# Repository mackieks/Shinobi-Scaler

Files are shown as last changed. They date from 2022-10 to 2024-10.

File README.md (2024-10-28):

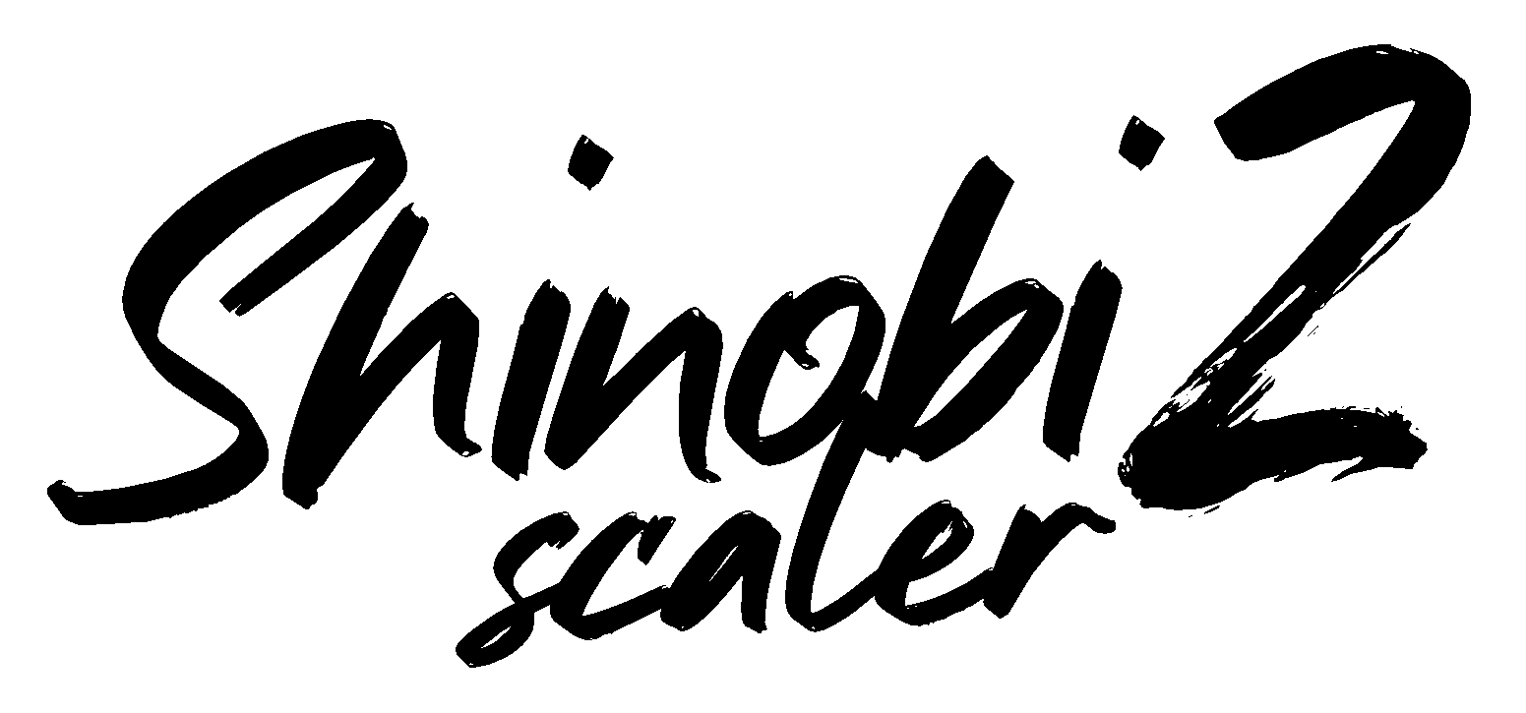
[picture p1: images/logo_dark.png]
<picture> <source media="(prefers-color-scheme: dark)" srcset="https://github.com/mackieks/Shinobi-Scaler/blob/shinobi-2/images/logo_light.png">  </picture> 

Shinobi Scaler 2 is a reimagined, miniaturized GBS8200 for portablizers. Like the original GBS8200, it can convert 240p and 480i RGBs to 480p/720p/960p/1080p VGA, making it perfect for connecting retro video game consoles to modern LCDs.

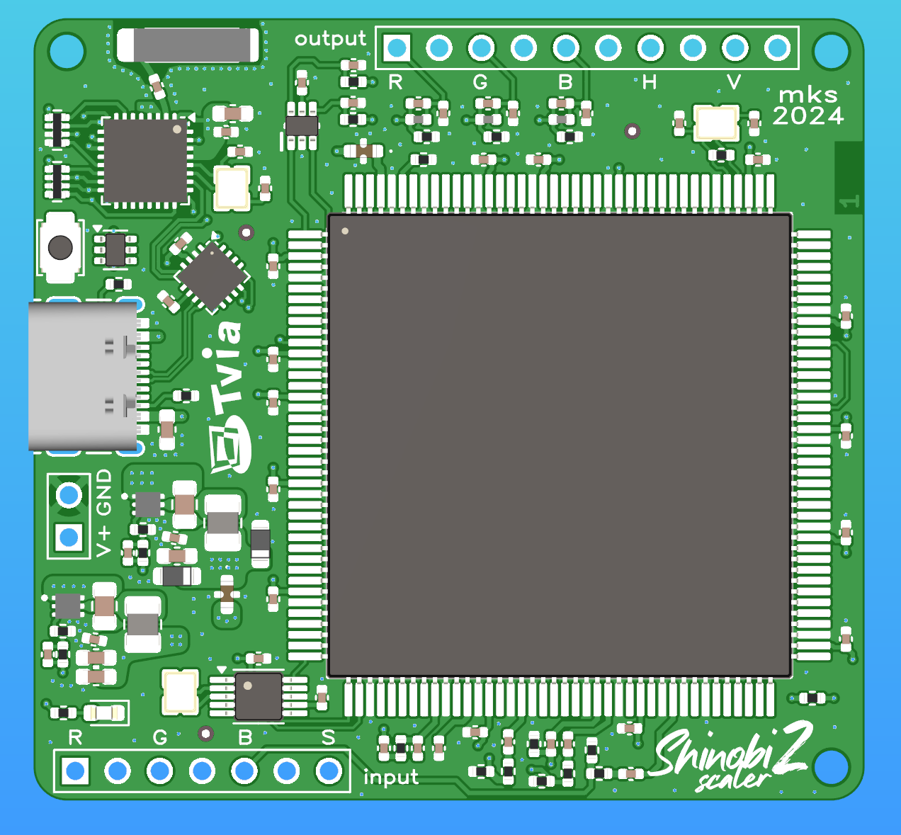
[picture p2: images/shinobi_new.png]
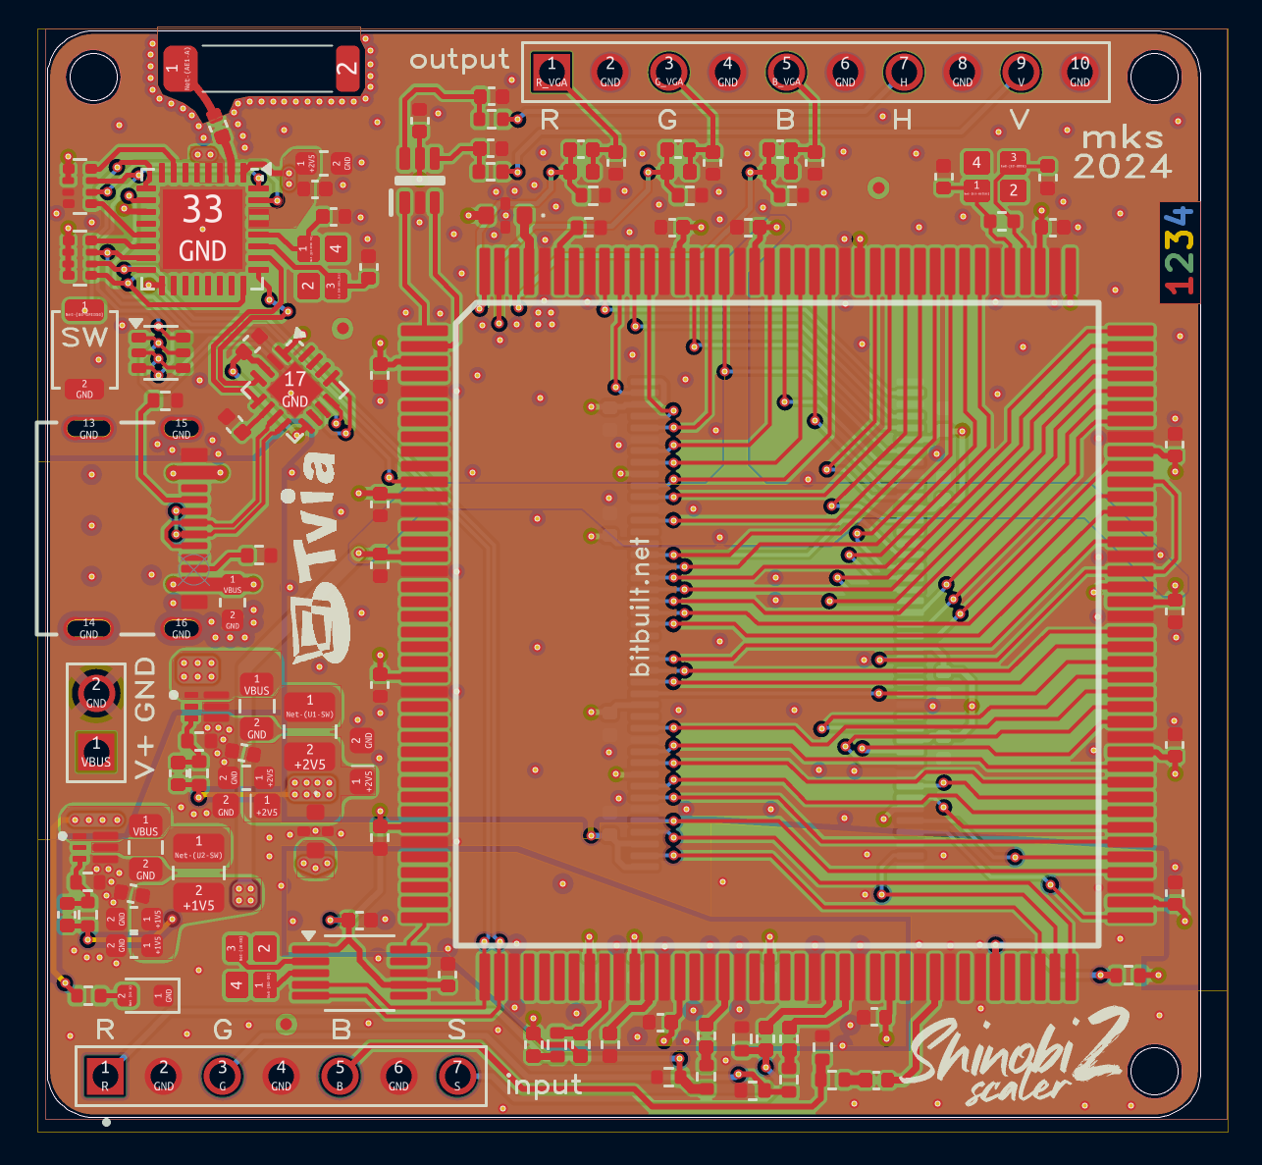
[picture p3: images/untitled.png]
  

## Features
- [x] 50 x 47mm 4-layer PCB (designed in KiCAD 8.99)
- [x] Compatible with [rama's GBS-Control](https://github.com/ramapcsx2/gbs-control)
- [x] 240p/480i RGBs input; 480p/720p/960p/1080p RGBHV/VGA/YPbPr output
- [x] 0.1" PTHs for power and IO (can be mounted with pin headers on a carrier PCB)
- [x] TV5725 scaler IC and 64Mbit SDRAM from GBS8200
- [x] Integrated ESP8285 with Wi-Fi chip antenna
- [x] Integrated CH343P for programming
- [x] Integrated Si5351A clock generator
- [x] Power from any 2.5V - 5.5V source (including 1S li-ion)
- [x] Draws 1.2W, half the power of Shinobi 1!


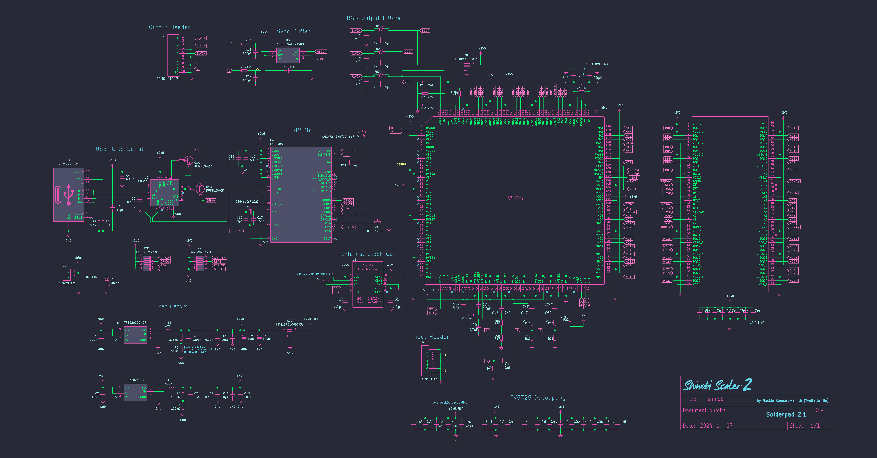
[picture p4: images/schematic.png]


## Gallery
Shinobi 2 PCB

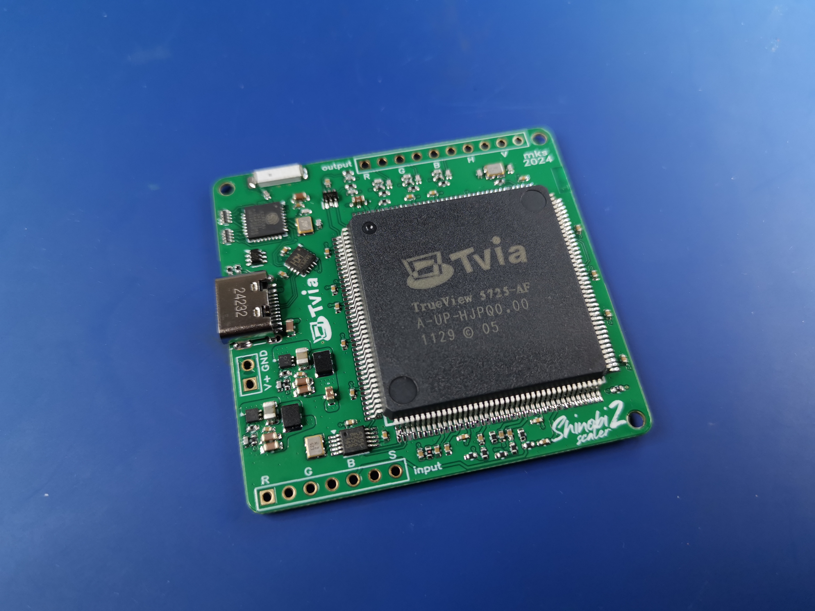
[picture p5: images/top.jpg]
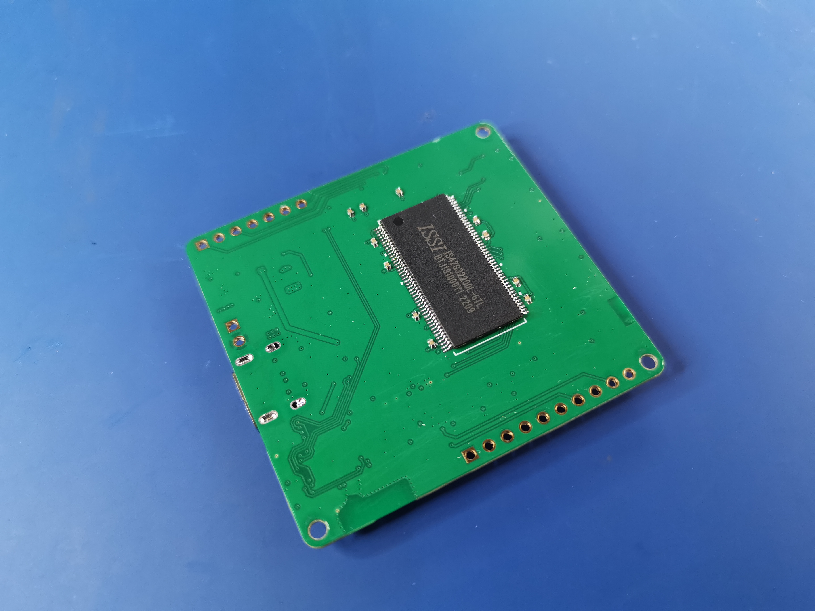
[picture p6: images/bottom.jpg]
  

1Chip SNES RGBs upscaled to 640x480 VGA, displayed on ZJ050NA-08C LCD

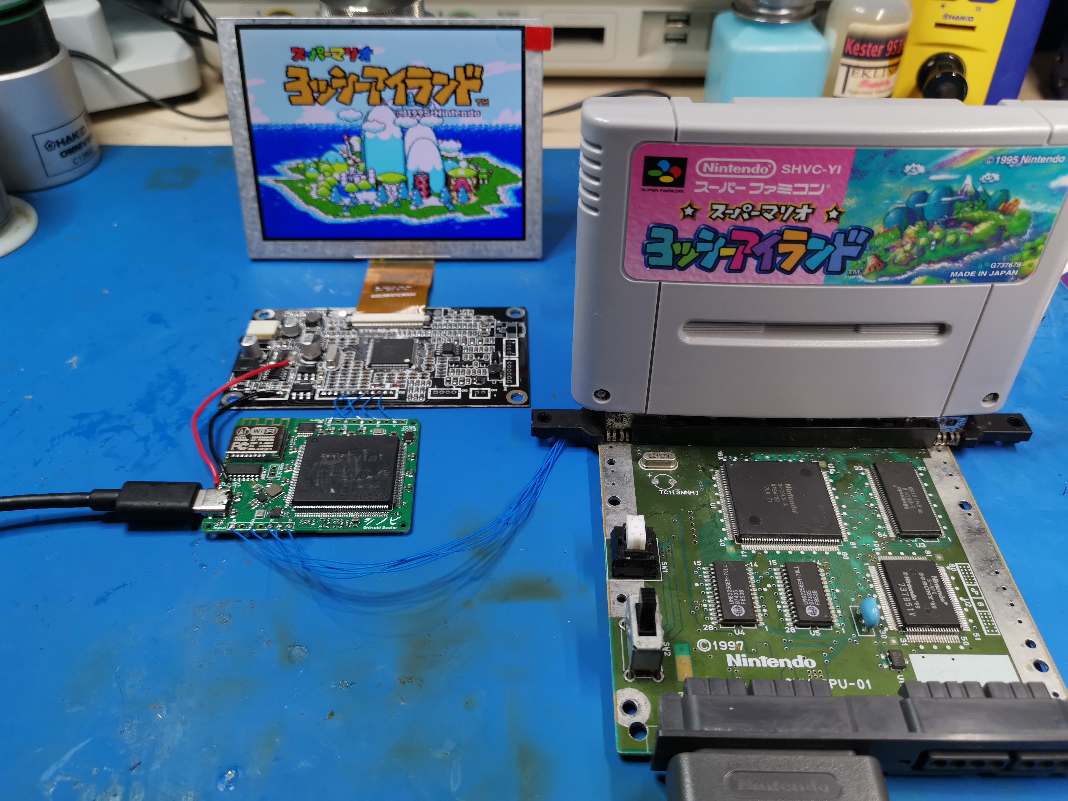
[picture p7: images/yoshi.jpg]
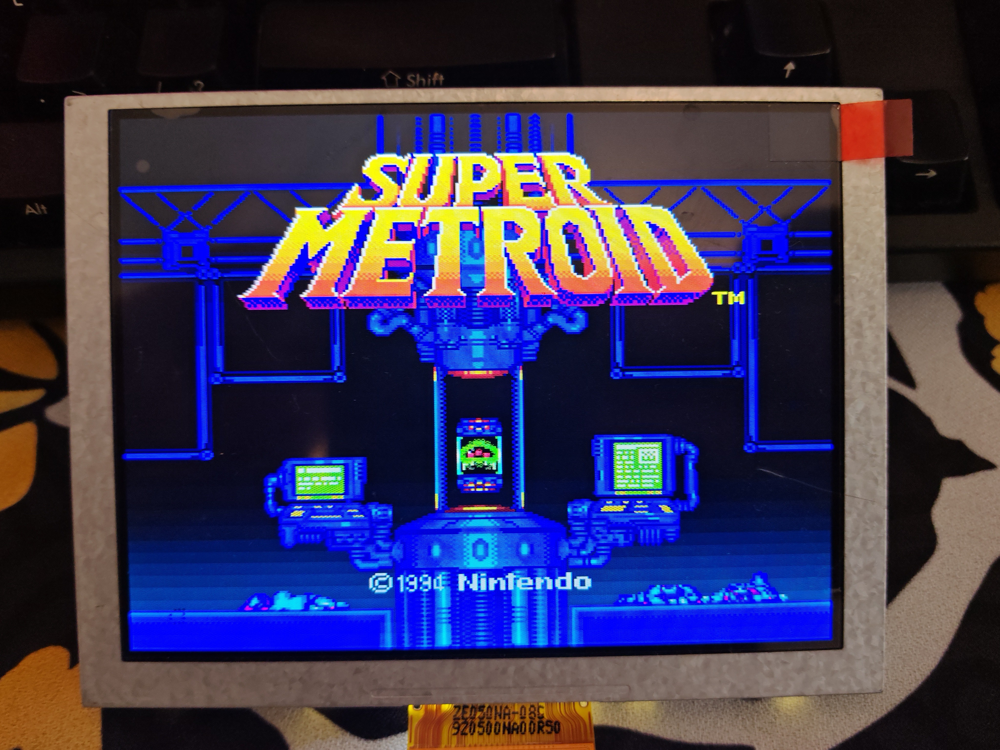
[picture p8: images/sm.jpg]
 

Shinobi 2 testing and power measurement

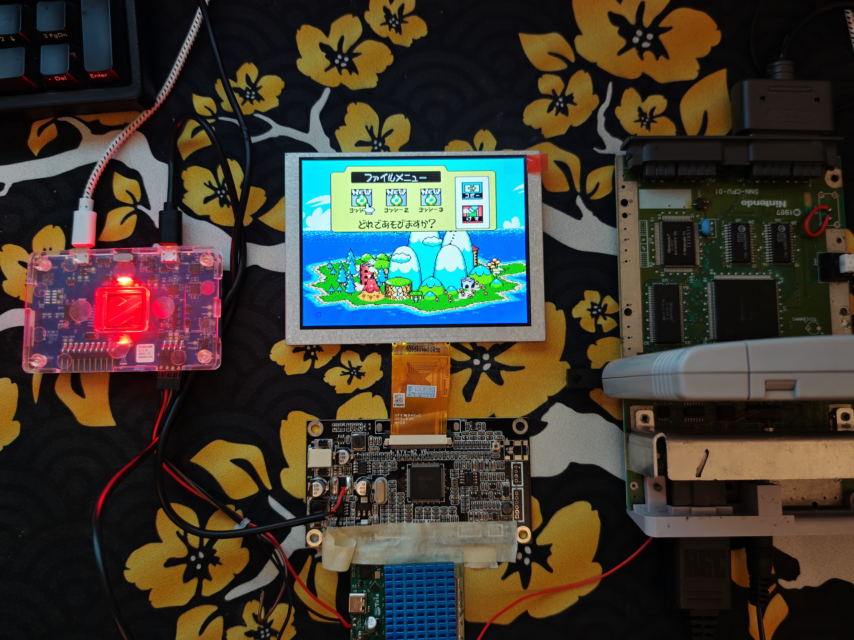
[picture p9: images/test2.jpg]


## Ordering
Recommended fabrication specs:
- 1mm-thick 4-layer PCB
- ENIG finish
- Solderpaste stencil for top side highly recommended

I maintain a [Mouser project](https://www.mouser.com/ProjectManager/ProjectDetail.aspx?AccessID=5e7ab48fda) with most of the BOM. 

You will still need to source a TV5725 and CH343P elsewhere. Cheap GBS8200s are available from AliExpress, eBay, DHGate, and Amazon if you'd like to harvest the TV5725 and SDRAM from one. [TV5725s](https://www.aliexpress.us/item/3256807282171835.html) are available from AliExpress. CH343Ps are sold on [LCSC](https://www.lcsc.com/product-detail/USB-ICs_WCH-Jiangsu-Qin-Heng-CH343P_C2846043.html) and [AliExpress](https://www.aliexpress.us/item/3256806693647102.html).

## Assembly
A ``bom.html`` file is included to facilitate assembly. Open it in your web browser and enjoy.

For a guide on how to assemble PCBs at home using a solderpaste stencil and hot plate, please see [this document from the Thundervolt repo.](https://github.com/mackieks/thundervolt/blob/main/hardware/ASSEMBLY.md)

## Programming
- Install the [CH343P driver](https://www.wch-ic.com/downloads/CH343SER_EXE.html).
- Plug USB-C into Shinobi 2
- Verify COM port (or your platform's equivalent) is enumerating
- Open GBS-Control release of your choice in Arduino IDE (these steps assume you have already installed requisite libraries, etc.)
- Set up Tools menu as shown, select CH343P port under Port menu, then program
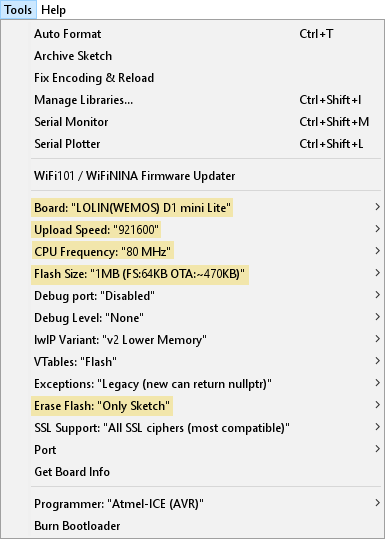
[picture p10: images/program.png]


- When programming is complete, unplug Shinobi 2 and power it back up to access GBS-Control Wi-Fi AP
- After setting up your presets, you can edit line 7211 of the Arduino sketch as shown, then recompile & reupload to totally disable Wi-Fi. This saves ~150mW


## To-do
- [ ] 

## License
[Solderpad Hardware License v2.1](https://solderpad.org/licenses/SHL-2.1/)

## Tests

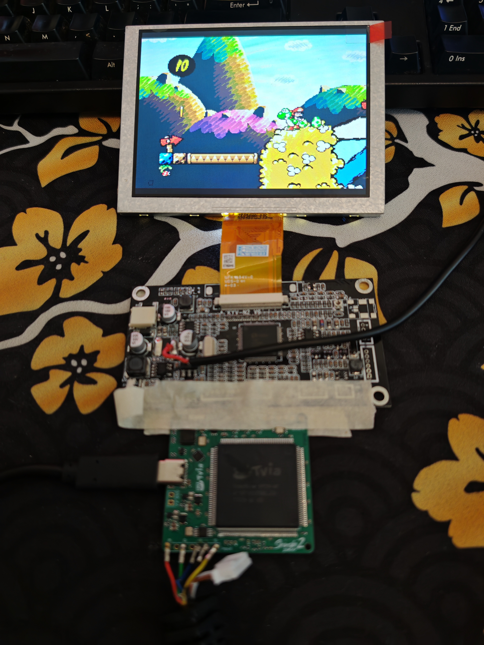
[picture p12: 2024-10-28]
images/test1.jpg

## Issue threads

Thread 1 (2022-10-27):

Audio support

maded2, 2022-10-27:
Fantastic project.   Any plans to add audio support? There's a forum thread on adding a cheap ADC so the audio is mixed into the hdmi signal for modern TV.

mackieks, 2022-10-28:
Hi! Glad you like it. Since the TV5725 doesn't have HDMI out, I'm assume you mean [integrating a VGA2HDMI converter?](https://www.vandoeselaar.com/tinkering/modding-a-gbs-8200/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)

While it's totally doable, it's not a priority of mine. Shinobi is mostly intended for portablizing where HDMI (and audio over HDMI) are less useful than VGA. Maybe someone else will take up the mantle and do a board spin.

Closed 2022-10-28.

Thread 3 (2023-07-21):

The output is rgbhv

ZeFoxii, 2023-07-21:
I have two questions, first what is the pcb you used to get the rgbhv to the lcd screen in your pictures?

Second let's say I build this and want to just make a mini gbs-c what would be the best way to get it to hdmi?

How hard would it be to add a ms9288a to hdmi connector to the rgbhv output. I'm new to this kinda thing so I'm asking.

ZeFoxii, 2023-07-21:
Do you think I could use a wii to hdmi adapter with a ms988a?

mackieks, 2023-07-21:
Hi! The LCD in the photos is a ZJ050NA-08C with a generic VGA driver board. Widely available on AliExpress, eBay, etc. Just search for that model number.

You can certainly add a VGA-to-HDMI converter if you'd like. There are a couple blog posts/tutorials floating around showing how to wire one up to a GBS-8200. They usually only need 5V, GND, and RGBHV.

Wii2HDMI adapters use YPbPr, not VGA, and while GBS-Control has an experimental YPbPr output feature, I haven't tested it and can't speak to its stability or compatibility.

ZeFoxii, 2023-07-22:
I have one last question when programming did you use the official GBSC settings or the settings provided by your picture?

mackieks, 2023-07-22:
If you're building a Shinobi Scaler, you need to use the settings shown in the README.

Closed 2023-07-22.

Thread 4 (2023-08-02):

YPBPR Output

ZeFoxii, 2023-08-02:
You stated in the read me

240p/480i RGBs input; 480p/720p/960p/1080p RGBHV/VGA/"YPbPr" output

How do I enable this output from the shinobi scaler?

ZeFoxii, 2023-08-02:
And once enabled what pins would I be soldering.

ZeFoxii, 2023-08-02:
My personal guess was just connect it to RGB and G would somehow through software start transmitting Y from the GBS-control software. But I don't know that as

A. I haven't built my shinobi scaler yet.

B. I don't want to damage hardware.

ZeFoxii, 2023-08-02:
I really love your project btw, so I apologize if I come off as rude.

mackieks, 2023-08-02:
Hello again! I'm glad you like the project. Like I said in #3, I haven't tested the YPbPr output myself. It's an experimental mode and compatibility with displays may be hit or miss.

But theoretically you just need to enable the "RGBHV/Component" toggle in the Settings menu.
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

Wiring should match the colors of YPbPr cables. So **R→Pr**, **B→Pb**, and **G→Y**.
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

Sync is embedded in the Y channel with component video, so you don't need to wire H or V.

ZeFoxii, 2023-08-03:
Perfect, that's exactly in line with what I was thinking. Yes! Thank you!

Closed 2023-08-02.

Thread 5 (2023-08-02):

BRD, file was updated but Gerber files were not

ZeFoxii, 2023-08-02:
I do not have, eagle, and trying to export it to a program like kicad gets rid of some things like the pad for program and a few milling paths. I'm not sure if the board was actually changed or not, could you please upload the updated Gerber files to reflect the change in the BRD file, if any.

mackieks, 2023-09-20:
Updated gerbers have been posted

Closed 2023-09-20.

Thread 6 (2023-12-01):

Help

ZeFoxii, 2023-12-01:
Hi I tried to build one of these and I'm at the end of my tether with this. I have burned myself and I was stubborn not asking this earlier. do you have some form of contact? I don't have the skill level to build one of these but I want one. I am also willing to send the parts I haven't fucked up/ what's left of the ones I did.

biggestsonicfan, 2023-12-01:
Where did you source your ESP-06s?

ZeFoxii, 2023-12-01:
From his link on AliExpress

biggestsonicfan, 2023-12-01:
You must have done it a long time ago because that link is gone and the store no longer carries them lol.

I am currently working on a fork of Shinobi to replace the ESP-06 and migrate the design to KiCad, although I haven't had much time to work on it lately.

There are other ways to have Shinobi made, alebit it at a very large expense. JLCPCB allows you to [consign parts](https://jlcpcb.com/help/article/245-How-to-consign-parts-to-JLCPCB), so you can ship them the parts to have them fabricated, though I do think the minimum order is 5 still, so adding up all the components on top of the PCB fabrication would be a fairly pricey endeavor.

I will most likely be doing a 5 board run once my KiCad version is finished.

ZeFoxii, 2023-12-01:
Well if you do make one I wouldn't mind buying it, but I also don't want what I don't have the skill to use to just sit around, if you have the skill to make it could I ship it to you pay labor etc.. and have you ship it back?

Because I burnt my hand pretty bad on multiple occasions trying to make this. And I really want one but I dont have the skill to do it.

ZeFoxii, 2023-12-06:
I feel like I could do it if the components weren't 0402, I felt confident with "everything else" 0603 tps module etc. maybe in the future I could make the pcb 1-2mm larger and pay someone on Fiverr to use 0603 instead of 0402

mackieks, 2023-12-06:
The sudden & unexpected disappearance of all ESP-06s has been a real bummer. I brought the ESP8266 and its support components into the design this past weekend and it looks promising. I'll try to upload a new supply-chain secure rev within a month or so.

Re: your assembly troubles, the board was never designed to be hand-soldered.

You should get a steel solderpaste stencil from JLCPCB or OSHStencils, place the components with tweezers or a vacuum pencil, and reflow with hot air, a hot plate, or a reflow oven. Magnification helps during placement but is by no means required.

biggestsonicfan, 2023-12-07:
> I brought the ESP8266 and its support components into the design this past weekend and it looks promising. I'll try to upload a new supply-chain secure rev within a month or so.

Ah so should I wait on the KiCad PR?

mackieks, 2023-12-14:
> Ah so should I wait on the KiCad PR?

Don't let me stop you! I probably won't finish up the new version until January. Also I'm implementing the ESP-06 1:1 with an ESP8266, not the ESP8285 that you were interested in.

ZeFoxii, 2024-01-19:
Hey just following up since you said January. Have you updated the board? Side note when you say ESP8266 do you mean the esp module or the one with drop mount pins?

biggestsonicfan, 2024-01-19:
It's just a replacement for the ESP-06 module. Instead of soldering the module on the board it will be the components that were inside the ESP-06 module directly on the board, adding more SMT components. The design change won't make the assembly of the board any easier, in fact it might make it slightly harder.

I did manage to locate some ESP-06 modules after months of looking and once they arrive I will verify that they are the correct version and then place an order for a batch the current revision of Shinobi Scaler PCBs. If they are not the correct version, I will wait until the 2024 design revision drops.

ZeFoxii, 2024-01-24:
Why not just use an esp12? Wouldn't it be basically the same thing just easy to solder?

biggestsonicfan, 2024-01-24:
You are free to fork the project and redesign with and ESP-12.

mackieks, 2024-10-28:
Shinobi 2, using a commodity ESP8285 and more efficient voltage regulators, has been tested and released.

Closed 2024-10-28.

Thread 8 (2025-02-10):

KiCAD version?

olalid, 2025-02-10:
Hi,

Thanks for a very interesting project.
I was trying to open the KiCad files, but I keep having issues where KiCad says I need a more recent version to open them.
Even though I tried using a more recent version than the latest stable release I keep getting that error message, saying that I need at least version 8.99, but there is no version 8.99 as far as I can see?
Can you please tell me which version you have used to generate the files?

olalid, 2025-02-10:
Never mind, works with vision 9.0.0-rc3.

Closed 2025-02-10.

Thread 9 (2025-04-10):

Sync signal for playstation 2

bagelrat, 2025-04-10:
Hello, wondering if anyone has experience using a Shinobi scaler for a playstation 2 -- to my knowledge, there is no cable solution that provides a sync signal (for RGBs). Want to know before ordering boards + assembling. Thank you!

luissantos, 2025-05-05:
I've been looking into using this board as well and from what I've seen you have to extract the sync from the composite or the Luna line output using a sync stripper.

I believe this is how this project https://github.com/jeffqchen/PS2VGA manages to connect the PS2 to into the GBS using the VGA input.

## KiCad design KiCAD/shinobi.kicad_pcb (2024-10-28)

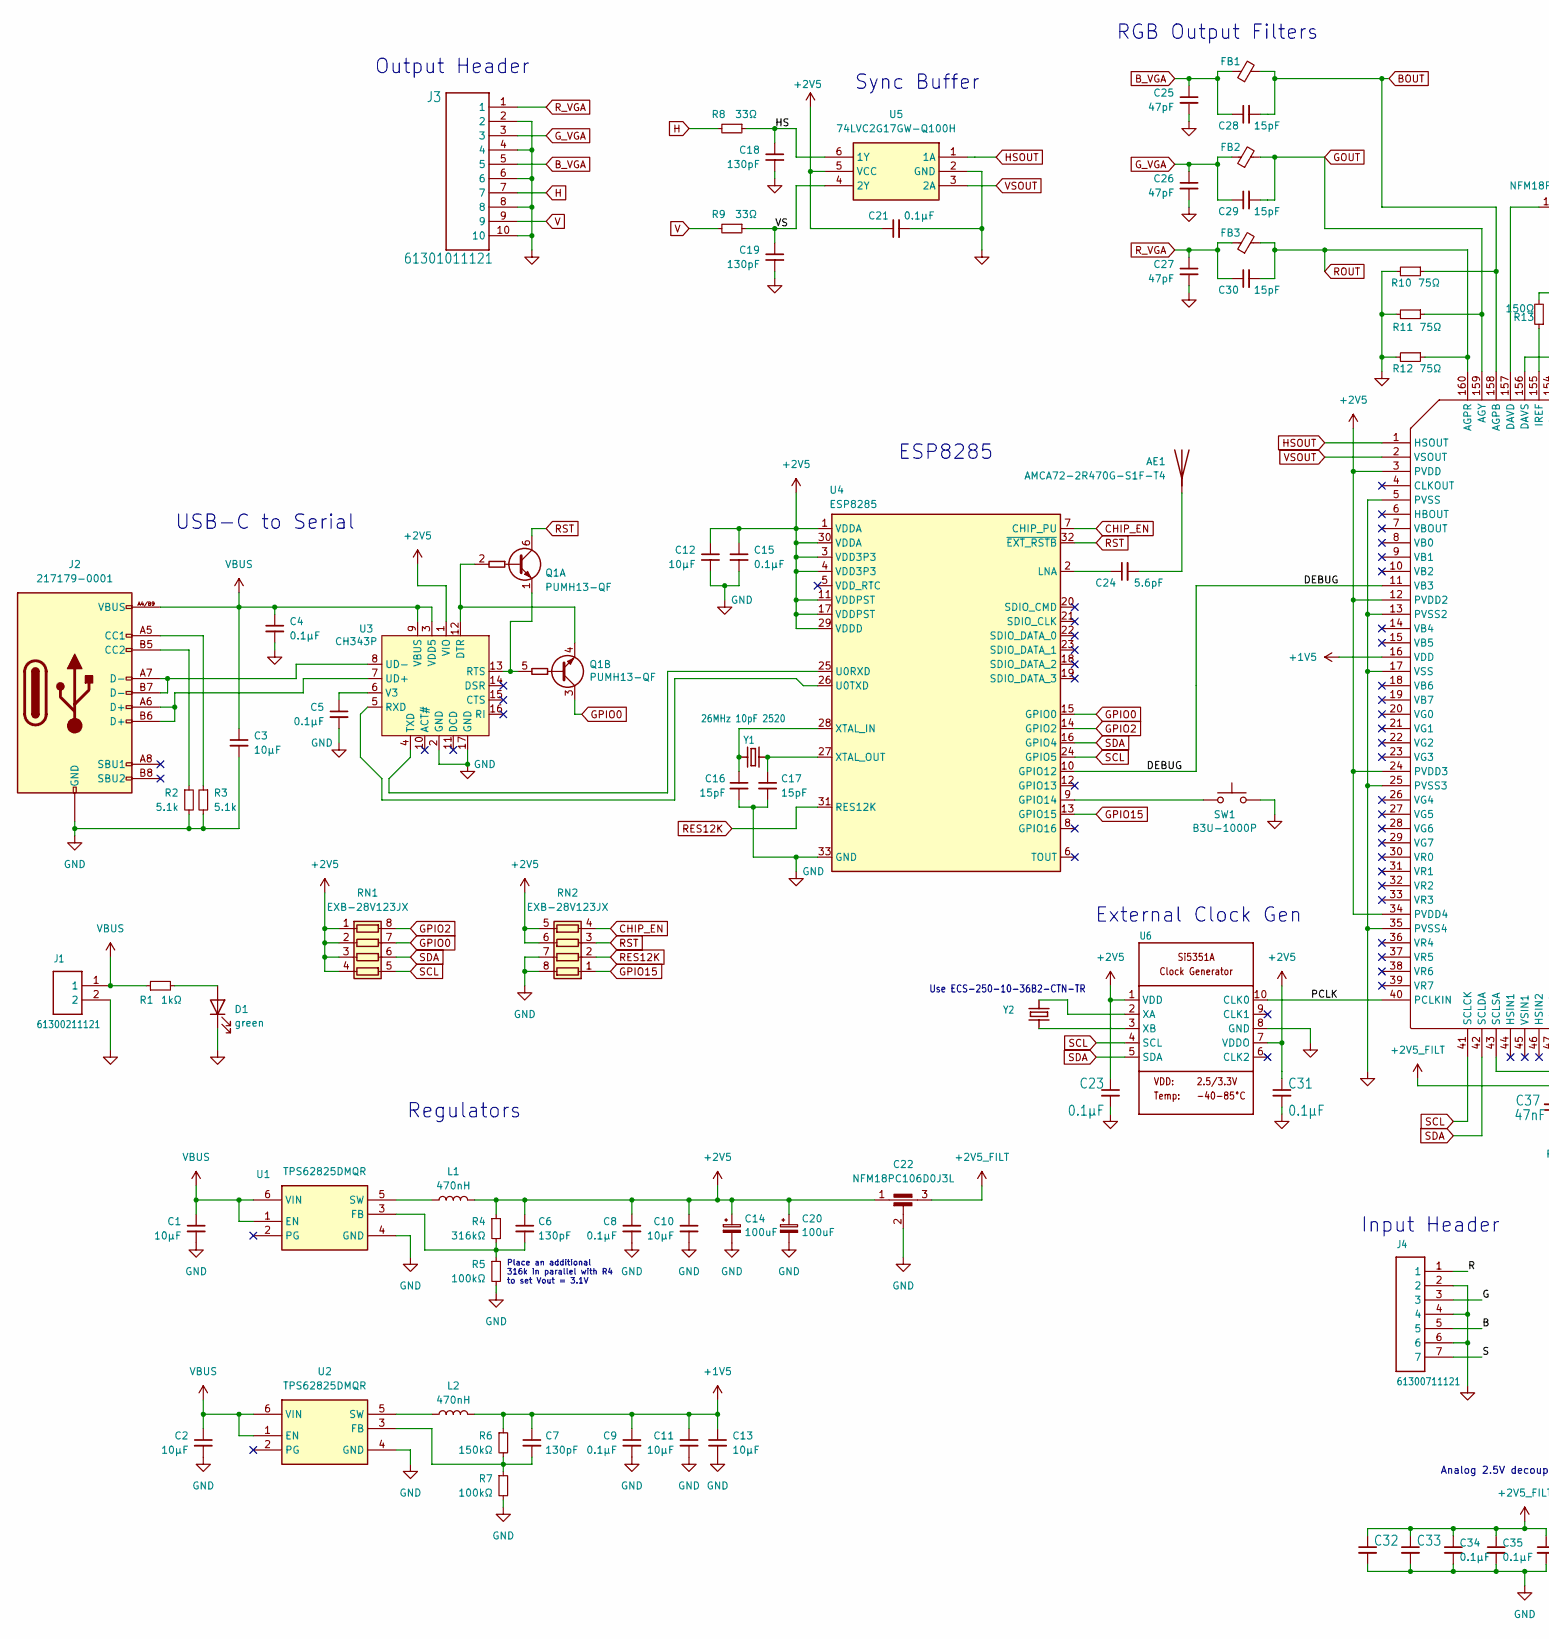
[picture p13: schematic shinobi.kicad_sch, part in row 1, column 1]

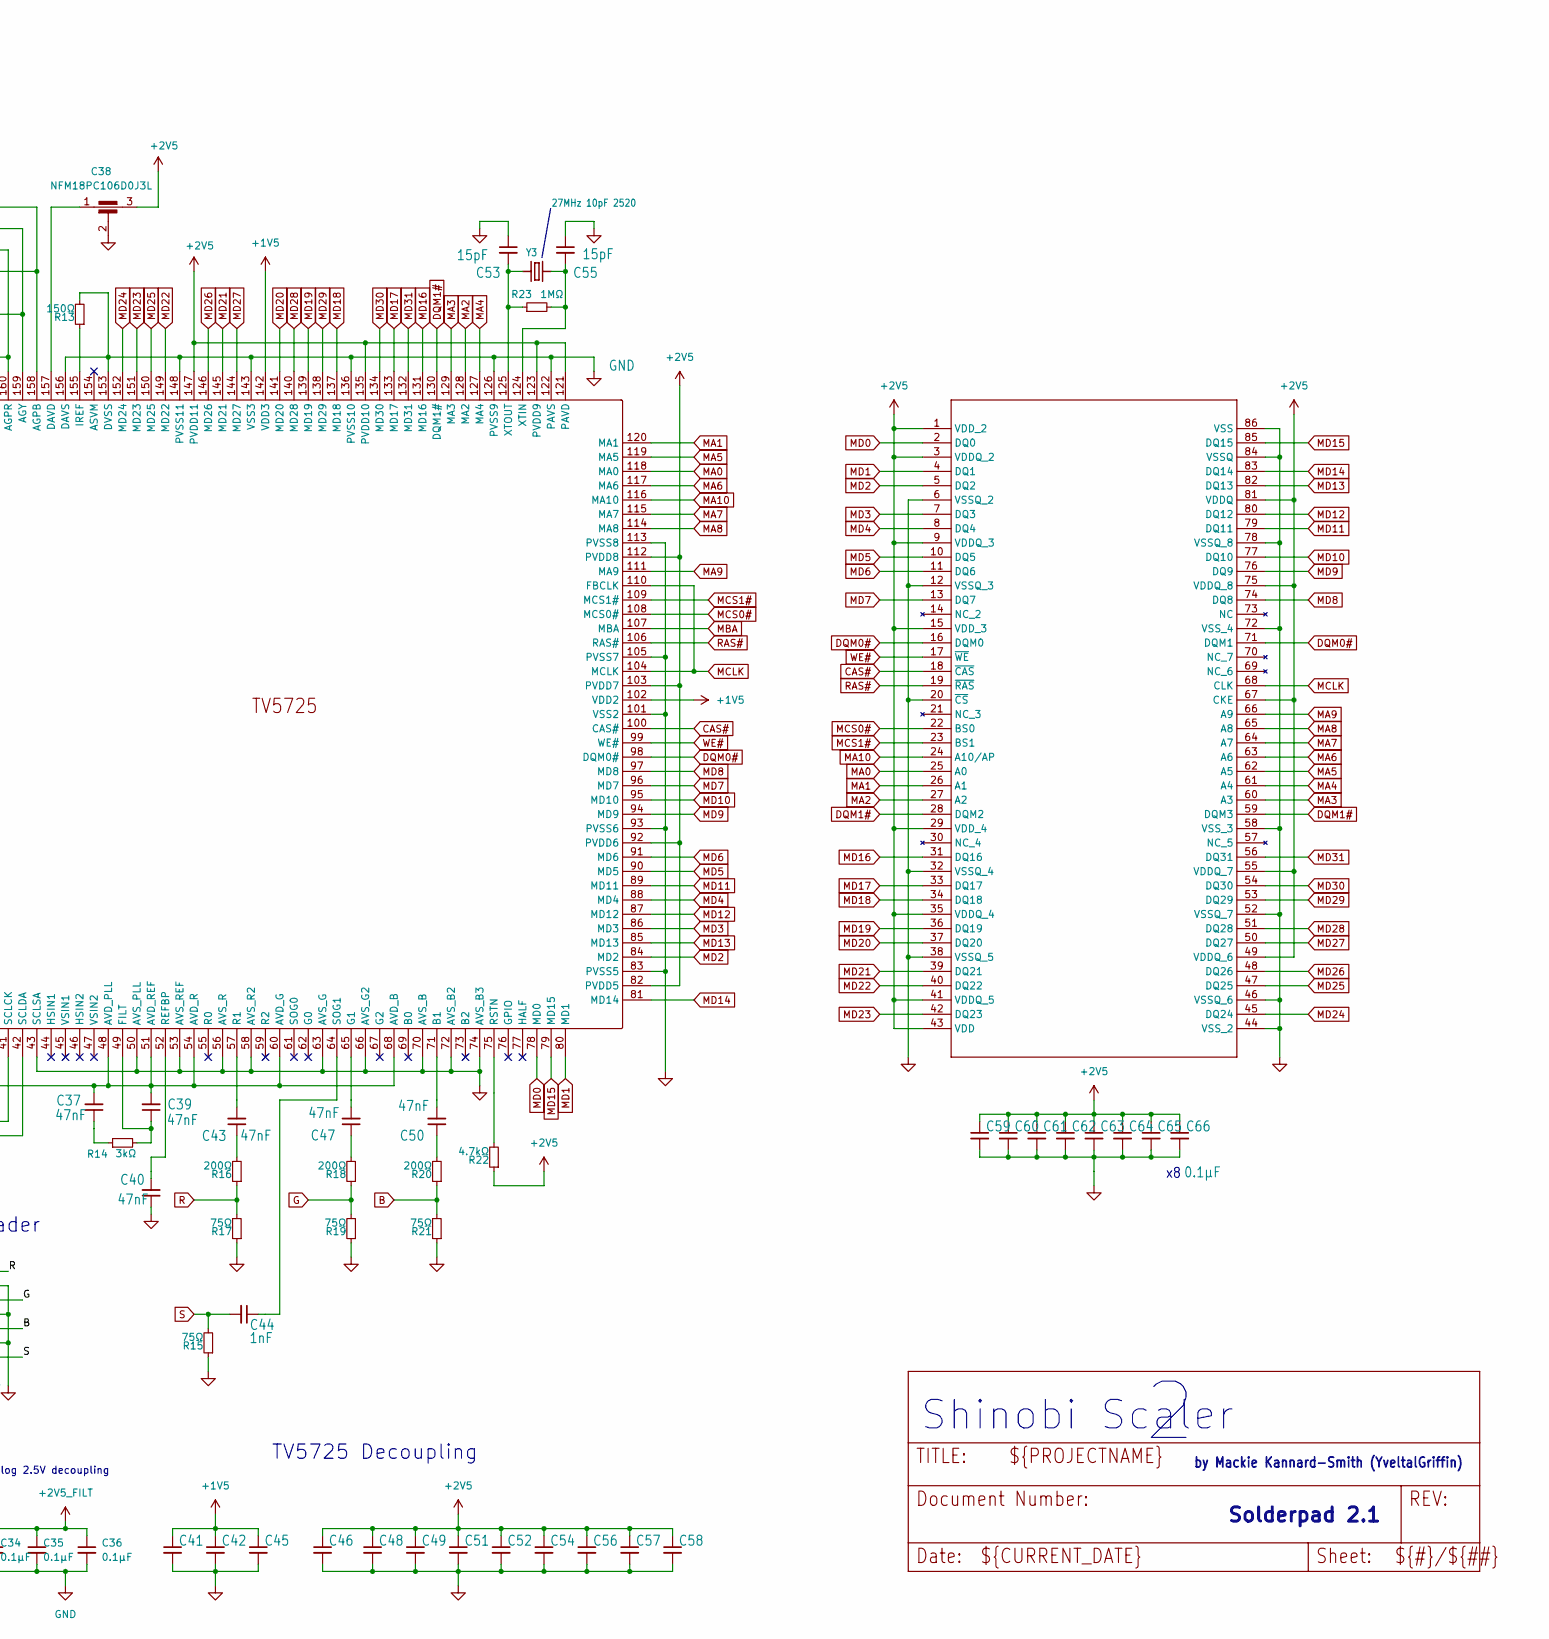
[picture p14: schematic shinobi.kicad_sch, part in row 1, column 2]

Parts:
AE1: AMCA72-2R470G-S1F-T4; AMCA722R470GS1FT4
C1, C2: 10μF; C_0805_2012Metric
C3, C10, C11, C12, C13: 10μF; C_0603_1608Metric
C4, C5, C8, C9, C15, C21, C23, C31, C32, C33, C34, C35, C36, C41, C42, C45, C46, C48, C49, C51, C52, C54, C56, C57, C58, C59, C60, C61, C62, C63, C64, C65, C66: 0.1μF; C_0402_1005Metric
C6, C7, C18, C19: 130pF; C_0402_1005Metric
C14, C20: 100uF; CP_EIA-2012-12_Kemet-R
C16, C17, C28, C29, C30, C53, C55: 15pF; C_0402_1005Metric
C22, C38: NFM18PC106D0J3L
C24: 5.6pF; C_0402_1005Metric
C25, C26, C27: 47pF; C_0402_1005Metric
C37, C39, C40, C43, C47, C50: 47nF; C_0402_1005Metric
C44: 1nF; C_0402_1005Metric
D1: green; LED_0603_1608Metric
FB1, FB2, FB3: BLM15BD221SN1D; L_0402_1005Metric
J1: 61300211121
J2: 217179-0001; 2171790001_MOL_650876
J3: 61301011121
J4: 61300711121; 61300711121_11687645
L1, L2: 470nH; L_1008_2520Metric
Q1: PUMH13-QF; SOT-363_SC-70-6
R1: 1kΩ; R_0402_1005Metric
R2, R3: 5.1k; R_0402_1005Metric
R4: 316kΩ; R_0402_1005Metric
R5, R7: 100kΩ; R_0402_1005Metric
R6: 150kΩ; R_0402_1005Metric
R8, R9: 33Ω; R_0402_1005Metric
R10, R11, R12, R15, R17, R19, R21: 75Ω; R_0402_1005Metric
R13: 150Ω; R_0402_1005Metric
R14: 3kΩ; R_0402_1005Metric
R16, R18, R20: 200Ω; R_0402_1005Metric
R22: 4.7kΩ; R_0402_1005Metric
R23: 1MΩ; R_0402_1005Metric
RN1, RN2: EXB-28V123JX; R_Array_Convex_4x0402
SW1: B3U-1000P; SW_SPST_B3U-1000P
U1, U2: TPS62825DMQR; TPS62825DMQT; Mouser Part Number TPS62825DMQR
U3: CH343P; QFN-16-1EP_3x3mm_P0.5mm_EP1.7x1.7mm
U4: ESP8285; QFN-32-1EP_5x5mm_P0.5mm_EP3.45x3.45mm
U5: 74LVC2G17GW-Q100H; SOT65P210X110-6N; Mouser Part Number 771-74LVC2G17GWQ100H
U6: SI5351A; MSOP-10_3x3mm_P0.5mm
U7: TV5725; PQFP160_650876
U8: W9864G2JH-6; WIN_TSOP-86_WIN_650876
Y1: 26MHz 10pF 2520; Crystal_SMD_2520-4Pin_2.5x2.0mm
Y2: 25MHz 10pF 2520; Crystal_SMD_2520-4Pin_2.5x2.0mm
Y3: 27MHz 10pF 2520; Crystal_SMD_2520-4Pin_2.5x2.0mm

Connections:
+1V5: C7.1, C9.1, C11.1, C13.1, C41.1, C42.1, C45.1, L2.2, R6.1, U7.16 (VDD), U7.102 (VDD2), U7.142 (VDD3)
+2V5: C6.1, C8.1, C10.1, C12.1, C14.1, C15.1, C20.1, C21.1, C22.1, C23.1, C31.1, C38.3, C46.1, C48.1, C49.1, C51.1, C52.1, C54.1, C56.1, C57.1, C58.1, C59.1, C60.1, C61.1, C62.1, C63.1, C64.1, C65.1, C66.1, L1.2, R4.1, R22.1, RN1.1 (R1.1), RN1.2 (R2.1), RN1.3 (R3.1), RN1.4 (R4.1), RN2.5 (R4.2), RN2.6 (R3.2), U3.1 (VIO), U4.1 (VDDA), U4.3 (VDD3P3), U4.4 (VDD3P3), U4.11 (VDDPST), U4.17 (VDDPST), U4.29 (VDDD), U4.30 (VDDA), U5.5 (VCC), U6.1 (VDD), U6.7 (VDDO), U7.3 (PVDD), U7.12 (PVDD2), U7.24 (PVDD3), U7.34 (PVDD4), U7.82 (PVDD5), U7.92 (PVDD6), U7.103 (PVDD7), U7.112 (PVDD8), U7.121 (PAVD), U7.123 (PVDD9), U7.135 (PVDD10), U7.147 (PVDD11), U8.1 (VDD_2), U8.3 (VDDQ_2), U8.9 (VDDQ_3), U8.15 (VDD_3), U8.29 (VDD_4), U8.35 (VDDQ_4), U8.41 (VDDQ_5), U8.43 (VDD), U8.49 (VDDQ_6), U8.55 (VDDQ_7), U8.67 (CKE), U8.75 (VDDQ_8), U8.81 (VDDQ)
+2V5_FILT: C22.3, C32.1, C33.1, C34.1, C35.1, C36.1, C37.2, C39.2, U7.48 (AVD_PLL), U7.51 (AVD_REF), U7.54 (AVD_R), U7.60 (AVD_G), U7.68 (AVD_B)
/DEBUG: U4.10 (GPIO12), U7.11 (VB3)
/HS: C18.1, R8.1, U5.6 (1Y)
/PCLK: U6.10 (CLK0), U7.40 (PCLKIN)
/VS: C19.1, R9.1, U5.4 (2Y)
B: J4.5, R20.1, R21.2
BOUT: C28.2, FB1.2, R10.1, U7.158 (AGPB)
B_VGA: C25.1, C28.1, FB1.1, J3.5
CAS#: U7.100 (CAS#), U8.18 (~CAS)
CHIP_EN: RN2.4 (R4.1), U4.7 (CHIP_PU)
DQM0#: U7.98 (DQM0#), U8.16 (DQM0), U8.71 (DQM1)
DQM1#: U7.130 (DQM1#), U8.28 (DQM2), U8.59 (DQM3)
G: J4.3, R18.1, R19.2
GND: C1.2, C2.2, C3.2, C4.2, C5.2, C8.2, C9.2, C10.2, C11.2, C12.2, C13.2, C14.2, C15.2, C16.2, C17.2, C18.2, C19.2, C20.2, C21.2, C22.2, C22.4, C23.2, C25.2, C26.2, C27.2, C31.2, C32.2, C33.2, C34.2, C35.2, C36.2, C38.2, C38.4, C40.1, C41.2, C42.2, C45.2, C46.2, C48.2, C49.2, C51.2, C52.2, C53.1, C54.2, C55.1, C56.2, C57.2, C58.2, C59.2, C60.2, C61.2, C62.2, C63.2, C64.2, C65.2, C66.2, D1.1 (K), J1.2, J2.1 (GND), J2.2 (GND), J2.3 (GND), J2.4 (GND), J2.13 (GND), J2.14 (GND), J2.15 (GND), J2.16 (GND), J2.A1/B12 (GND_2), J2.B1/A12 (GND), J2.S_1_H1 (GND), J2.S_1_H2 (GND), J2.S_2_H1 (GND), J2.S_2_H2 (GND), J2.S_3_H1 (GND), J2.S_3_H2 (GND), J2.S_4_H1 (GND), J2.S_4_H2 (GND), J3.2, J3.4, J3.6, J3.8, J3.10, J4.2, J4.4, J4.6, R2.2, R3.2, R5.2, R7.2, R10.2, R11.2, R12.2, R13.2, R15.1, R17.1, R19.1, R21.1, RN2.7 (R2.2), RN2.8 (R1.2), SW1.2, U1.4 (GND), U2.4 (GND), U3.2 (GND), U3.17 (GND), U4.33 (GND), U5.2 (GND), U6.8 (GND), U7.5 (PVSS), U7.13 (PVSS2), U7.17 (VSS), U7.25 (PVSS3), U7.35 (PVSS4), U7.43 (SCLSA), U7.50 (AVS_PLL), U7.53 (AVS_REF), U7.56 (AVS_R), U7.58 (AVS_R2), U7.63 (AVS_G), U7.66 (AVS_G2), U7.70 (AVS_B), U7.72 (AVS_B2), U7.74 (AVS_B3), U7.83 (PVSS5), U7.93 (PVSS6), U7.101 (VSS2), U7.105 (PVSS7), U7.113 (PVSS8), U7.122 (PAVS), U7.126 (PVSS9), U7.136 (PVSS10), U7.143 (VSS3), U7.148 (PVSS11), U7.153 (DVSS), U7.156 (DAVS), U8.6 (VSSQ_2), U8.12 (VSSQ_3), U8.20 (~CS), U8.32 (VSSQ_4), U8.38 (VSSQ_5), U8.44 (VSS_2), U8.46 (VSSQ_6), U8.52 (VSSQ_7), U8.58 (VSS_3), U8.72 (VSS_4), U8.78 (VSSQ_8), U8.84 (VSSQ), U8.86 (VSS)
GOUT: C29.2, FB2.2, R11.1, U7.159 (AGY)
GPIO0: Q1.3 (C2), RN1.7 (R2.2), U4.15 (GPIO0)
GPIO2: RN1.8 (R1.2), U4.14 (GPIO2)
GPIO15: RN2.1 (R1.1), U4.13 (GPIO15)
G_VGA: C26.1, C29.1, FB2.1, J3.3
H: J3.7, R8.2
HSOUT: U5.1 (1A), U7.1 (HSOUT)
MA0: U7.118 (MA0), U8.25 (A0)
MA1: U7.120 (MA1), U8.26 (A1)
MA2: U7.128 (MA2), U8.27 (A2)
MA3: U7.129 (MA3), U8.60 (A3)
MA4: U7.127 (MA4), U8.61 (A4)
MA5: U7.119 (MA5), U8.62 (A5)
MA6: U7.117 (MA6), U8.63 (A6)
MA7: U7.115 (MA7), U8.64 (A7)
MA8: U7.114 (MA8), U8.65 (A8)
MA9: U7.111 (MA9), U8.66 (A9)
MA10: U7.116 (MA10), U8.24 (A10/AP)
MBA: U7.107 (MBA)
MCLK: U7.104 (MCLK), U7.110 (FBCLK), U8.68 (CLK)
MCS0#: U7.108 (MCS0#), U8.22 (BS0)
MCS1#: U7.109 (MCS1#), U8.23 (BS1)
MD0: U7.78 (MD0), U8.2 (DQ0)
MD1: U7.80 (MD1), U8.4 (DQ1)
MD2: U7.84 (MD2), U8.5 (DQ2)
MD3: U7.86 (MD3), U8.7 (DQ3)
MD4: U7.88 (MD4), U8.8 (DQ4)
MD5: U7.90 (MD5), U8.10 (DQ5)
MD6: U7.91 (MD6), U8.11 (DQ6)
MD7: U7.96 (MD7), U8.13 (DQ7)
MD8: U7.97 (MD8), U8.74 (DQ8)
MD9: U7.94 (MD9), U8.76 (DQ9)
MD10: U7.95 (MD10), U8.77 (DQ10)
MD11: U7.89 (MD11), U8.79 (DQ11)
MD12: U7.87 (MD12), U8.80 (DQ12)
MD13: U7.85 (MD13), U8.82 (DQ13)
MD14: U7.81 (MD14), U8.83 (DQ14)
MD15: U7.79 (MD15), U8.85 (DQ15)
MD16: U7.131 (MD16), U8.31 (DQ16)
MD17: U7.133 (MD17), U8.33 (DQ17)
MD18: U7.137 (MD18), U8.34 (DQ18)
MD19: U7.139 (MD19), U8.36 (DQ19)
MD20: U7.141 (MD20), U8.37 (DQ20)
MD21: U7.145 (MD21), U8.39 (DQ21)
MD22: U7.149 (MD22), U8.40 (DQ22)
MD23: U7.151 (MD23), U8.42 (DQ23)
MD24: U7.152 (MD24), U8.45 (DQ24)
MD25: U7.150 (MD25), U8.47 (DQ25)
MD26: U7.146 (MD26), U8.48 (DQ26)
MD27: U7.144 (MD27), U8.50 (DQ27)
MD28: U7.140 (MD28), U8.51 (DQ28)
MD29: U7.138 (MD29), U8.53 (DQ29)
MD30: U7.134 (MD30), U8.54 (DQ30)
MD31: U7.132 (MD31), U8.56 (DQ31)
unnamed: AE1.1 (A), C24.2
unnamed: C37.1, R14.1
unnamed: C43.1, R16.2
unnamed: C47.1, R18.2
unnamed: C50.1, R20.2
unnamed: D1.2 (A), R1.2
unnamed: J2.A5 (CC1), R3.1
unnamed: J2.B5 (CC2), R2.1
unnamed: Q1.2 (B1), Q1.4 (E2), U3.12 (DTR)
unnamed: Q1.1 (E1), Q1.5 (B2), U3.13 (RTS)
unnamed: C6.2, R4.2, R5.1, U1.3 (FB)
unnamed: L1.1, U1.5 (SW)
unnamed: C7.2, R6.2, R7.1, U2.3 (FB)
unnamed: L2.1, U2.5 (SW)
unnamed: U3.5 (RXD), U4.26 (U0TXD)
unnamed: U3.4 (TXD), U4.25 (U0RXD)
unnamed: J2.A6 (D+), J2.B6 (D+), U3.7 (UD+)
unnamed: J2.A7 (D-), J2.B7 (D-), U3.8 (UD-)
unnamed: C5.1, U3.6 (V3)
unnamed: SW1.1, U4.9 (GPIO14)
unnamed: C24.1, U4.2 (LNA)
unnamed: C16.1, U4.28 (XTAL_IN), Y1.1
unnamed: C17.1, U4.27 (XTAL_OUT), Y1.3 (2)
unnamed: U6.2 (XA), Y2.3 (2)
unnamed: U6.3 (XB), Y2.1
unnamed: C50.2, U7.71 (B1)
unnamed: C38.1, U7.157 (DAVD)
unnamed: C39.1, R14.2, U7.49 (FILT)
unnamed: C47.2, U7.65 (G1)
unnamed: R13.1, U7.155 (IREF)
unnamed: C43.2, U7.57 (R1)
unnamed: C40.2, U7.52 (REFBP)
unnamed: R22.2, U7.75 (RSTN)
unnamed: C44.1, U7.64 (SOG1)
unnamed: C55.2, R23.2, U7.124 (XTIN), Y3.3 (2)
unnamed: C53.2, R23.1, U7.125 (XTOUT), Y3.1
R: J4.1, R16.1, R17.2
RAS#: U7.106 (RAS#), U8.19 (~RAS)
RES12K: RN2.2 (R2.1), U4.31 (RES12K)
ROUT: C30.2, FB3.2, R12.1, U7.160 (AGPR)
RST: Q1.6 (C1), RN2.3 (R3.1), U4.32 (~EXT_RSTB)
R_VGA: C27.1, C30.1, FB3.1, J3.1
S: C44.2, J4.7, R15.2
SCL: RN1.5 (R4.2), U4.24 (GPIO5), U6.4 (SCL), U7.41 (SCLCK)
SDA: RN1.6 (R3.2), U4.16 (GPIO4), U6.5 (SDA), U7.42 (SCLDA)
V: J3.9, R9.2
VBUS: C1.1, C2.1, C3.1, C4.1, J1.1, J2.A4/B9 (VBUS), J2.B4/A9 (VBUS), R1.1, U1.1 (EN), U1.6 (VIN), U2.1 (EN), U2.6 (VIN), U3.3 (VDD5), U3.9 (VBUS)
VSOUT: U5.3 (2A), U7.2 (VSOUT)
WE#: U7.99 (WE#), U8.17 (~WE)

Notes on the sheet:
Shinobi Scaler
Analog 2.5V decoupling
Use ECS-250-10-36B2-CTN-TR
External Clock Gen
Solderpad 2.1
Input Header
USB-C to Serial
Place an additional 316k in parallel with R4 to set Vout = 3.1V
Output Header
Regulators
Sync Buffer
TV5725 Decoupling
by Mackie Kannard-Smith (YveltalGriffin)
ESP8285
RGB Output Filters

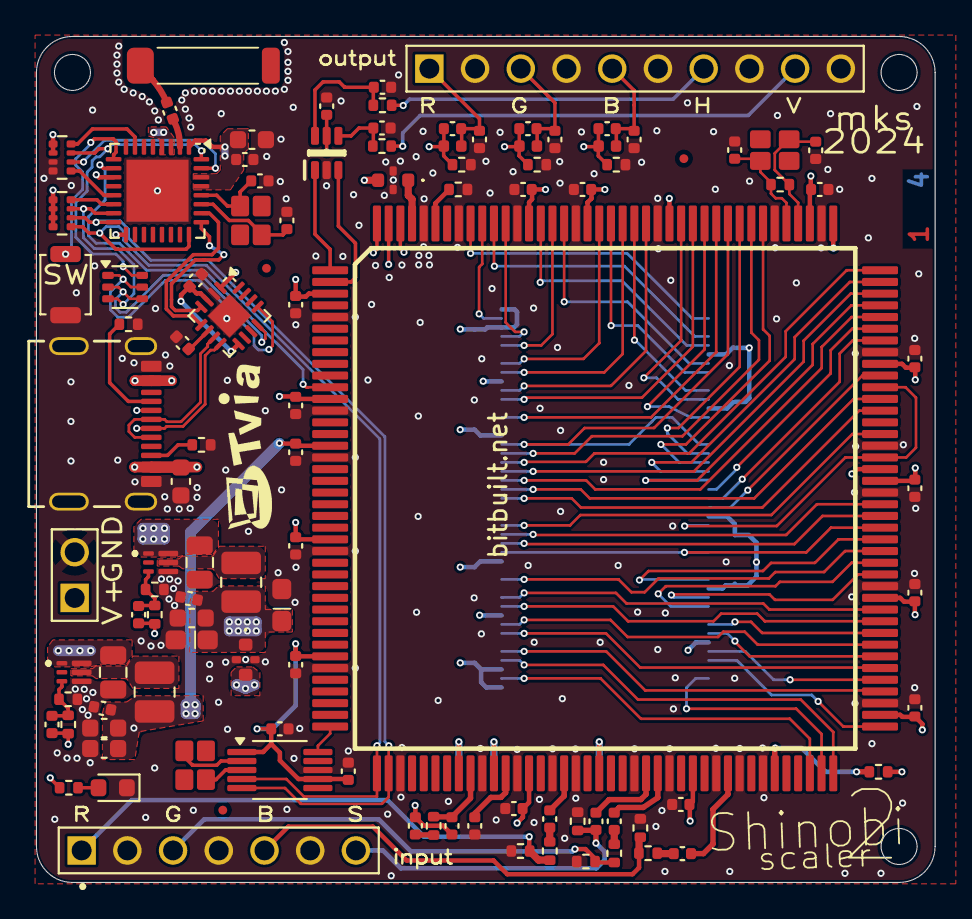
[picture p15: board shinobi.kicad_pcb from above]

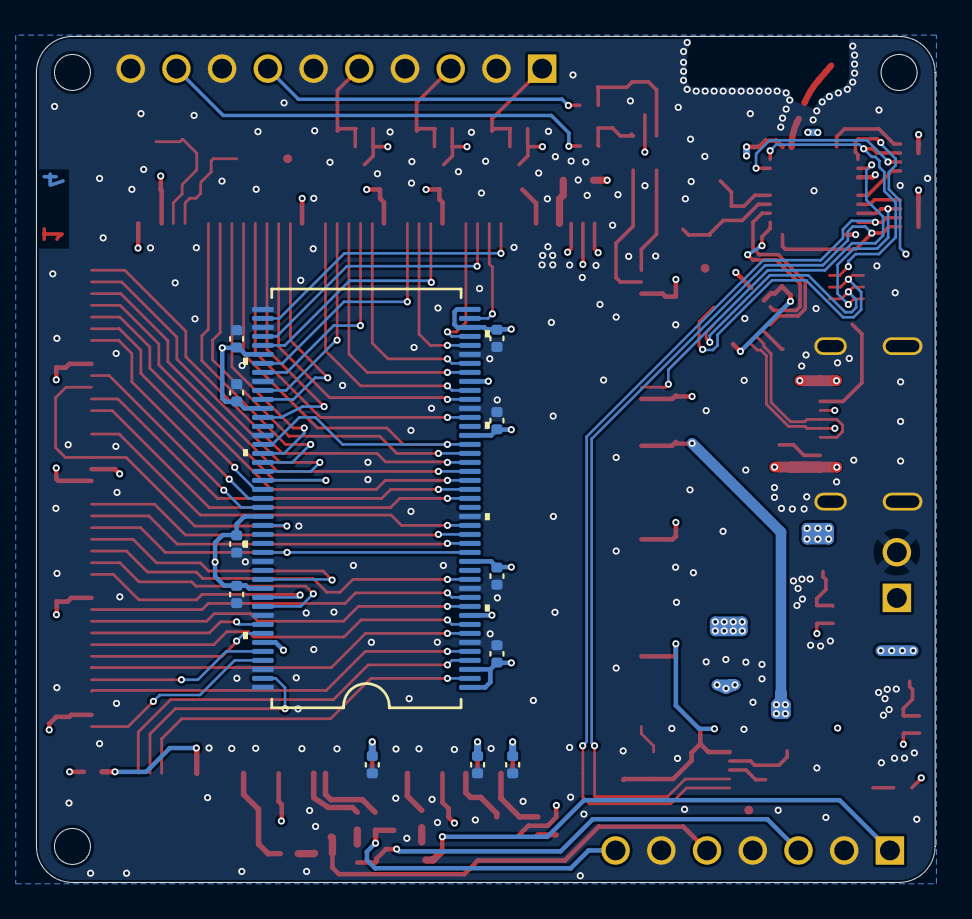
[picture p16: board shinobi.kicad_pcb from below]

Board: 4 copper layers, 49.9 x 47.0 mm, 115 parts (12 on the bottom side), 118 nets.

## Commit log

2022-10-24 add source files
    [shinobi.brd, shinobi.sch]
2022-10-24 update images
    [shinobi.brd]
2022-10-25 update images, add eagle palette script
    [shinobi.brd, shinobi.sch]
2022-10-25 add image and dxf
    [shinobi.brd, shinobi.dxf]
2022-10-25 fix gerber issue, update schematic.png
    [shinobi.brd, shinobi.sch]
2022-12-05 Add MCAD (unfinished)
    -PCB STEP
    -Unfinished case file
2023-03-17 update board
    [shinobi.brd, shinobi.sch]
2023-03-18 update brd
    [shinobi.brd, shinobi.sch]
2023-07-21 update with correct ferrite beads
    [shinobi.brd, shinobi.sch]
2023-09-20 board update
    - minor tweak to cap placement (fixes soldermask aperture issue)
    -gerbers updated
    -iBOM updated
    [shinobi.brd]
2024-01-23 update to solderpad license
2024-07-17 WIP Shinobi 2
    [shinobi.brd, shinobi.kicad_pcb, shinobi.kicad_sch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]
2024-07-18 shinobi2 routing
    [shinobi.kicad_pcb, shinobi.kicad_sch]
2024-07-18 Update PCB and BOM
    [shinobi.kicad_pcb, shinobi.kicad_sch, shinobiBOM.csv]
2024-10-23 embed fonts, layout tweaks
    [shinobi.kicad_pcb, shinobi.kicad_sch]
2024-10-23 more minor layout tweaks
    [shinobi.kicad_pcb]
2024-10-23 tweak artwork
    [shinobi.kicad_pcb]
2024-10-28 small updates
    [shinobi.kicad_pcb, shinobi.kicad_sch]
2024-10-28 updating files
    [BOM-shinobi.csv, shinobi case v5.step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]
